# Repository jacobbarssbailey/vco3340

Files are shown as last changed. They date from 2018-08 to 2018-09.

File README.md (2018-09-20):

# VCO3340
This project provides tested plans for a 6HP Eurorack-format CEM3340 [CoolAudio 3340] VCO synthesizer module.

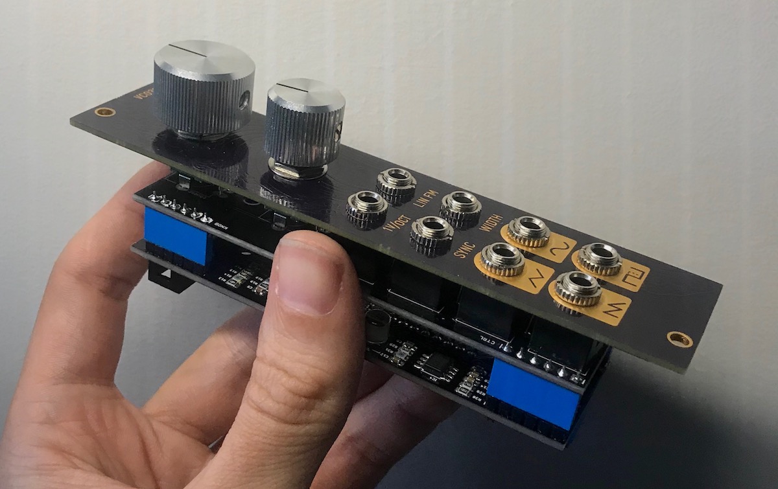
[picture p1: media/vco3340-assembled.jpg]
Assembled module


### Inputs
- V/OCT: Exponential (1V per octave) pitch input
- Lin FM: Linear frequency modulation
- Sync: Hard sync oscillator to external signal; requires audio-rate signal at approx. ±5V.
- Width: Set duty cycle of pulse output from 0-100% with ±2.5V signal; normalled to 0V, i.e. square wave output

### Outputs
All oscillator outputs (Sine, Triangle, Sawtooth, and Pulse) range from ±5V. The pulse input width is controlled by the Width input, and by default is a 50% duty cycle, i.e. Square wave.

## BOM 

Qty | Value            | Device                  | Package             | Parts                                                |
--- | ---------------- | ----------------------- | ------------------- | ---------------------------------------------------- |
2   | 10KΩ             | Pot (Alpha 9mm)         | 6mm                 | COURSE, FINE                                         |
8   | 3.5mm Jacks      |                         | Thonkiconn          | LINFM, PULSE, SAW, SIN, SYNC, TRI, V/OCT, WIDTH      |
4   | M06              | 2.54mm header           | Pin                 | CTRL, KNOB, OUT, POWER                               |
4   | M06              | 2.54mm header           | Socket              | CTRL, KNOB, OUT, POWER                               |
1   | M08X2            | 2.54mm header           | Pin                 | EXPANSION                                            |
3   |                  | 2.54mm                  | Jumper              |                                                      |
1   | M05x2            | 2.54mm header           | Shrouded            | POWER                                                |
2   | 100Ω             | Resistor                | 0805                | R1, R22                                              |
1   | 390Ω             | Resistor                | 0805                | R36                                                  |
2   | 470Ω             | Resistor                | 0805                | R9, R19                                              |
1   | 1KΩ              | Resistor                | 0805                | R32                                                  |
2   | 2.2KΩ            | Resistor                | 0805                | R34, R40                                             |
2   | 3.6KΩ            | Resistor                | 0805                | R23, R25                                             |
1   | 5.6KΩ            | Resistor                | 0805                | R2, R21                                              |
8   | 10KΩ             | Resistor                | 0805                | R5, R10, R27, R35, R38, R39, R41, R42                |
1   | 24KΩ             | Resistor                | 0805                | R20                                                  |
1   | 47KΩ             | Resistor                | 0805                | R3                                                   |
2   | 80KΩ             | Resistor                | 0805                | R28, R29                                             |
5   | 100KΩ            | Resistor                | 0805                | R4, R15, R16, R24, R30                               |
4   | 200KΩ            | Resistor                | 0805                | R14, R18, R26, R31                                   |
1   | 150KΩ            | Resistor                | 0805                | R6                                                   |
3   | 1MΩ              | Resistor                | 0805                | R7, R11, R13                                         |
1   | 1.5MΩ            | Resistor                | 0805                | R8                                                   |
2   | 1.0nF            | Capacitor               | 0805                | C1, C2                                               |
1   | 1.25nF           | Capacitor (CG0)         | 0805                | C6                                                   |
2   | 10nF             | Capacitor               | 0805                | C4, C5                                               |
11  | 100nF            | Capacitor               | 0805                | C3, C10, C11, C12, C13, C14, C15, C18, C19, C21, C22 |
2   | 1µF              | Capacitor               | 0805                | C8, C9                                               |
4   | 47µF             | Capacitor (Pol)         | PANASONIC_C         | C16, C17, C20, C23                                   |
1   | 10KΩ             | Trimpot                 | 2.54mm Multiturn    | SCALE                                                |
1   | 20KΩ             | Trimpot                 | 2.54mm Multiturn    | HIGHFREQ                                             |
1   | 50KΩ             | Trimpot                 | 2.54mm Multiturn    | SYMMETRY                                             |
1   | 100KΩ            | Trimpot                 | 2.54mm Multiturn    | DRIVE                                                |
2   |                  | DIODE                   | SOD-123             | D4, D5                                               |
3   |                  | DIODE                   | SOD-323             | D1, D2, D3                                           |
2   | 3904             | Transistor (NPN)        | SOT23               | Q1, Q2                                               |
1   |                  | LM79L05A                | SOT89               | U1                                                   |
1   |                  | MC78L05A                | SOT89               | U2                                                   |
1   | TL071            | OPAMP-SINGLE            | SO08                | IC1                                                  |
1   |                  | V3340/CEM3340           | SO16                | IC2                                                  |
1   |                  | LM397                   | SOT23-5             | IC3                                                  |
2   | TL072            | OPAMP-DUAL              | SO08                | IC4, IC5                                             |

## Notes on assembly:
1. The rear expansion header is not optional; the V/Oct, Pulse Width, and Soft Sync inputs *must* be connected to ground for proper operation
1. Non-shrouded headers may be used for the Power connector, but this makes it easier to invert the cable polarity, with potentially unpleasant results.

## First time setup
The four trim potentiometers must be set up before use. The following procedure is recommended:
1. Confirm that the V/Oct, Pulse Width, and Soft Sync inputs on the expansion header are connected to the neighboring ground pin (with jumpers)
1. Turn HIGHFREQ all the way down. The middle pin should be shorted to ground.
1. Adjust SCALE until V/Oct input tracks at 1V per octave from 40-60Hz to ≅2Khz. This step is the most difficult, but its critical for tuning. If available, compare against a reference VCO with good tracking. Alternative methods include measuring the pulse output with a frequency counter, or measuring with an external tuner.
1. Adjust HIGHFREQ up until higher frequencies track equally well.
1. Measure the SINE output. Adjust DRIVE and SYMMETRY until the output sounds like a Sine Wave. Using an Oscilloscope may make this easiest, but its not critical and your ears are an equally good reference.

## Expansion header

While the module is an excellent standalone module, the rear expansion header may be used to add additional controls or further manipulate outputs.

It can provide power rails to a sister module, but the ±5V rails should be limited to <50mA.

The external V/Oct pin duplicates the front-panel input. The Width input sets the default pulse width. The Soft Sync input is ready to use as is, and expects ±5V audio rate signals as input.

All output waveforms are provided for additional waveshaping.

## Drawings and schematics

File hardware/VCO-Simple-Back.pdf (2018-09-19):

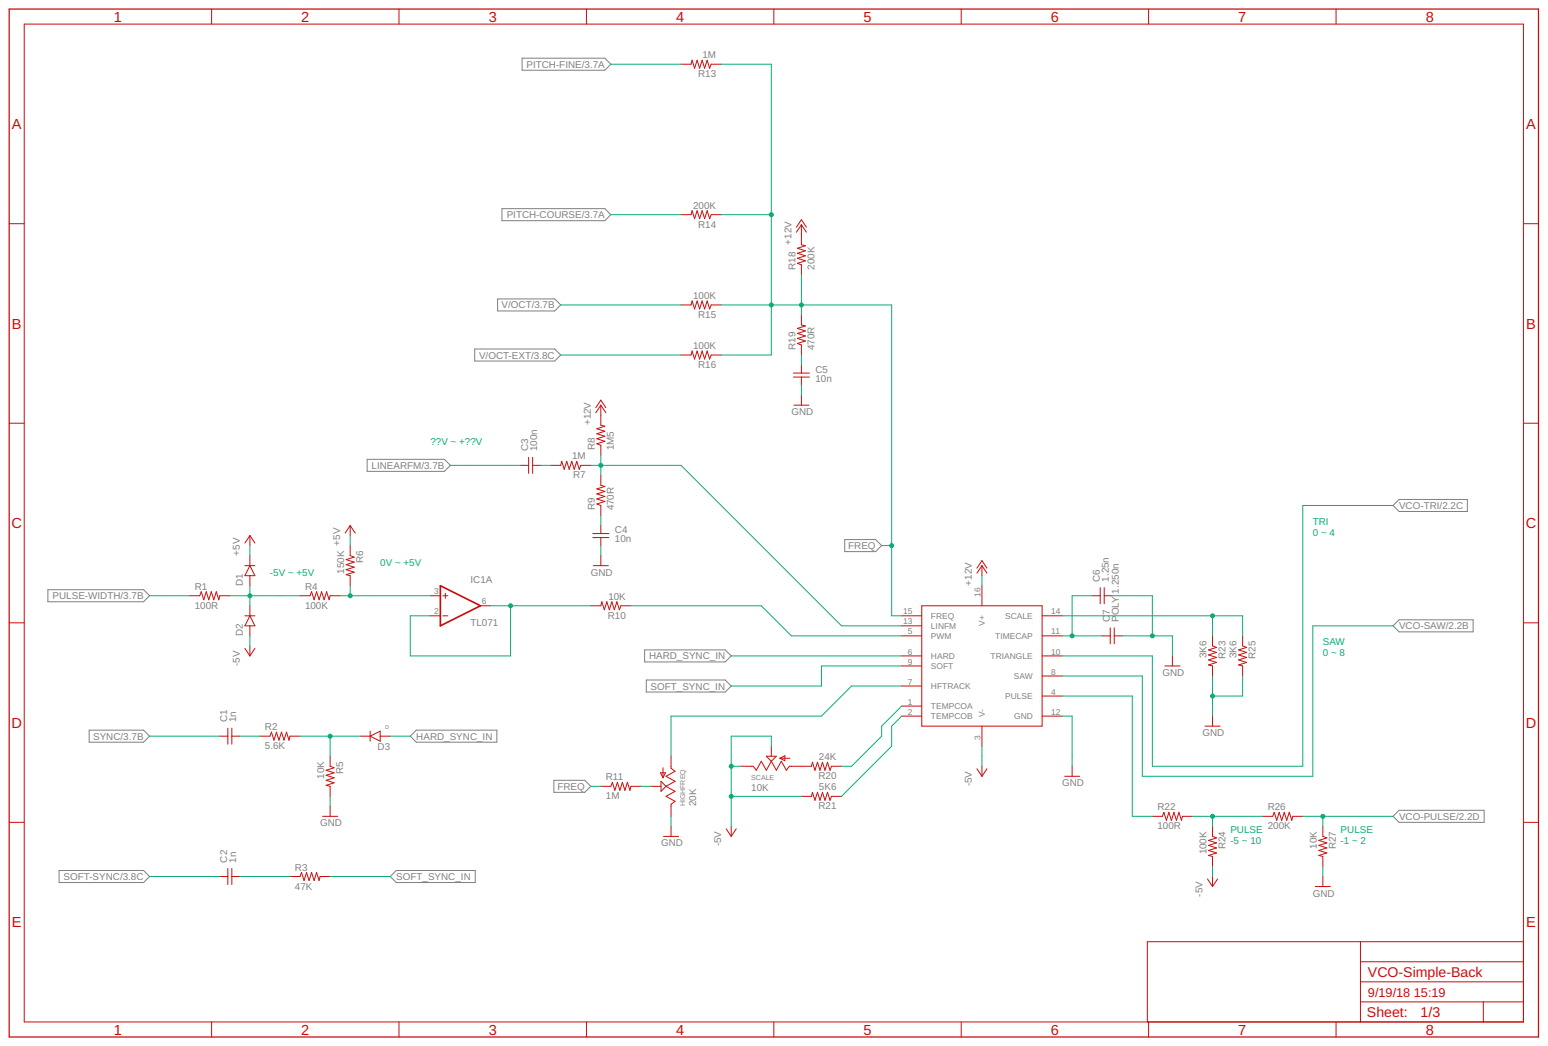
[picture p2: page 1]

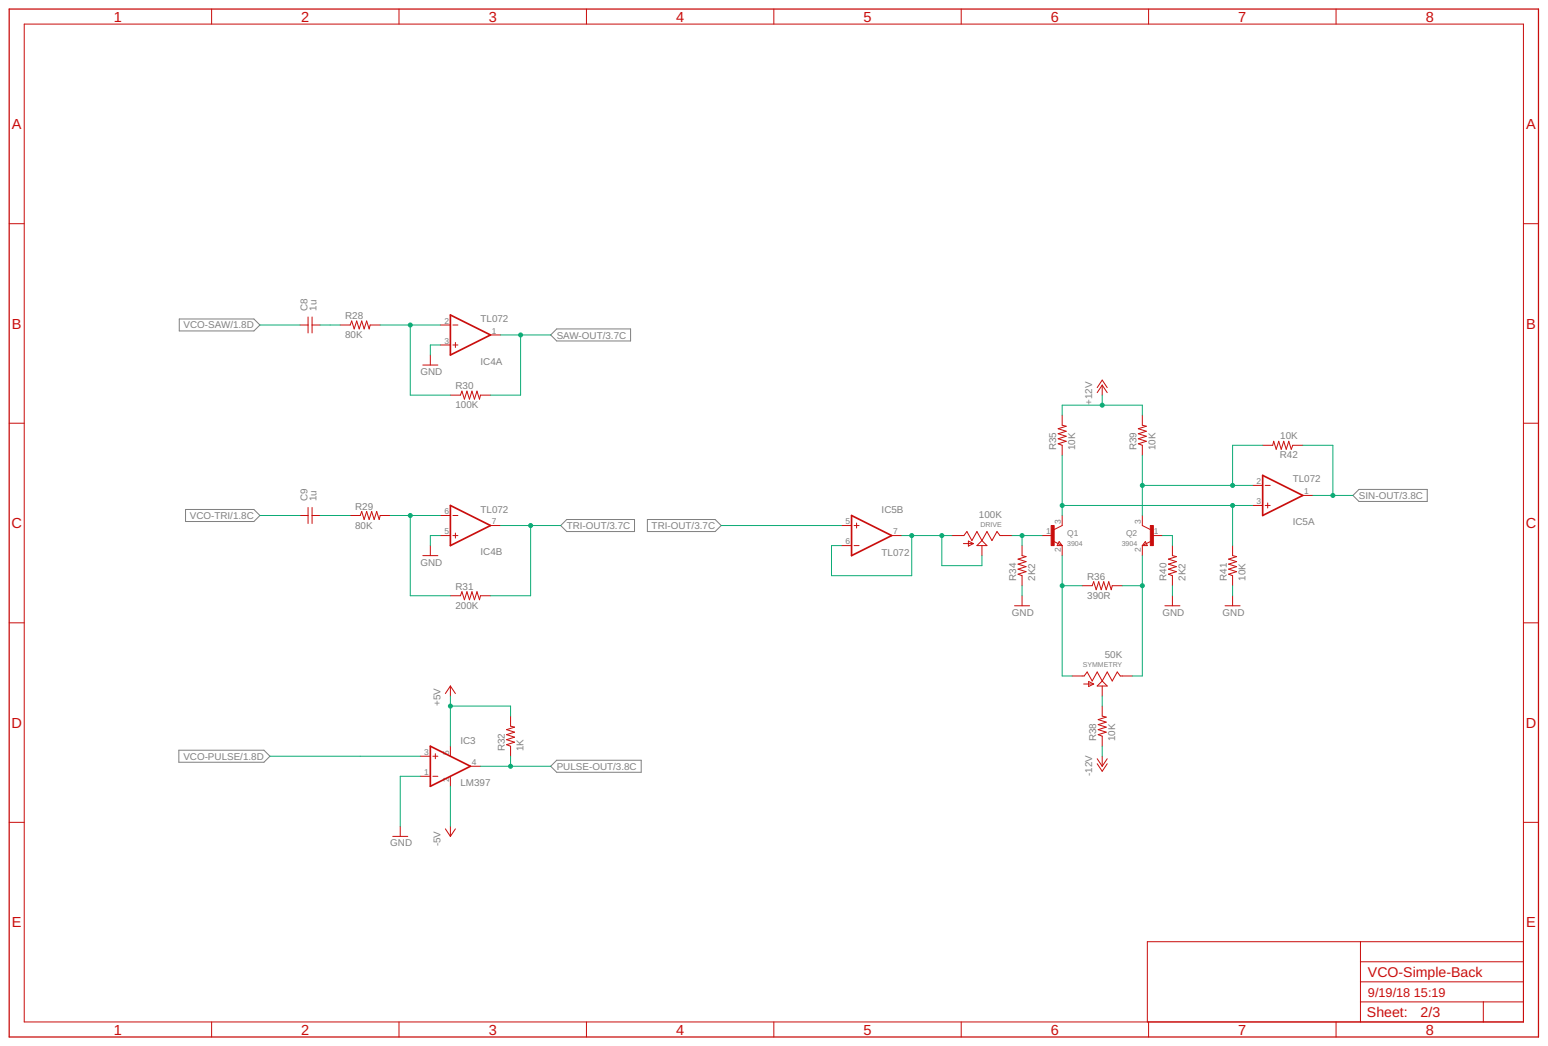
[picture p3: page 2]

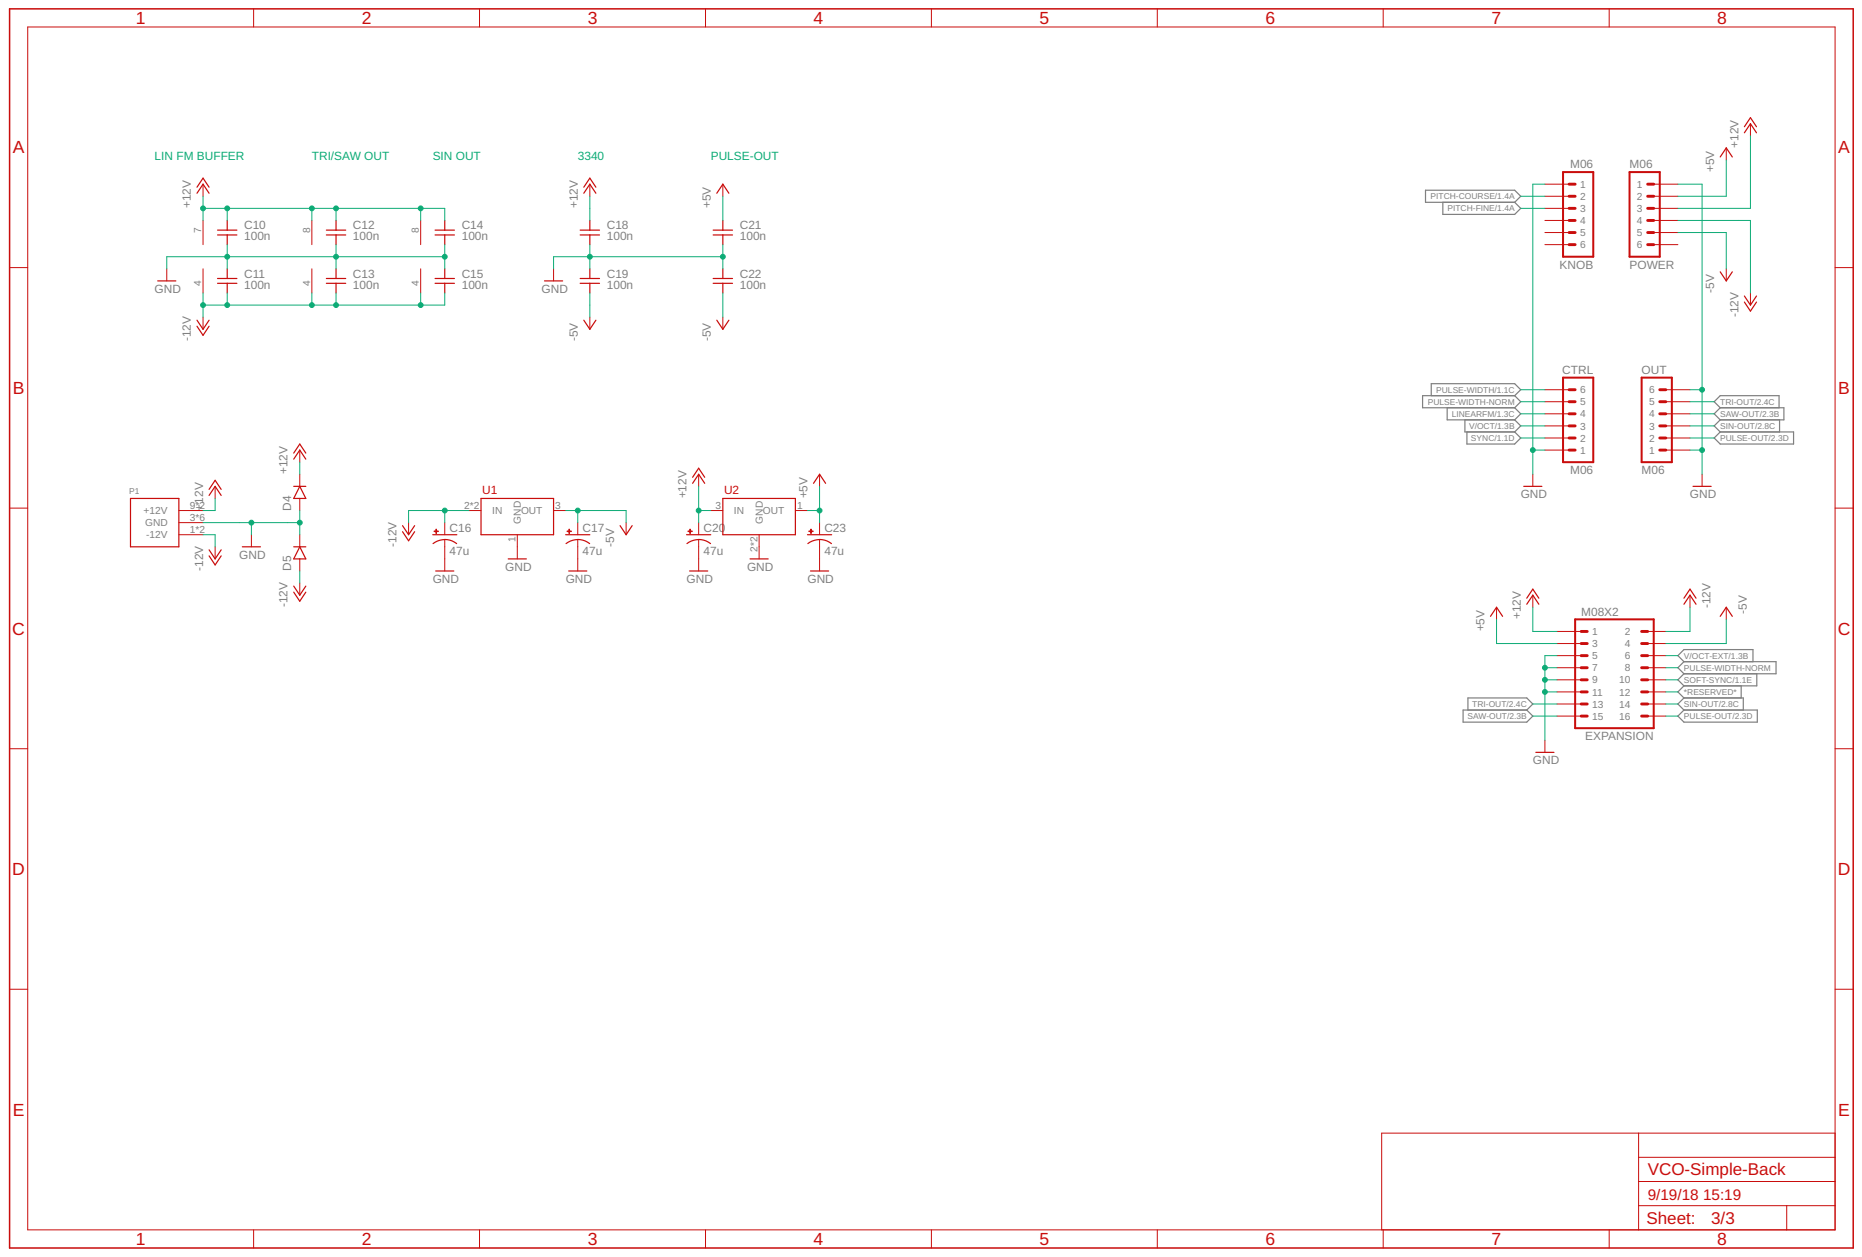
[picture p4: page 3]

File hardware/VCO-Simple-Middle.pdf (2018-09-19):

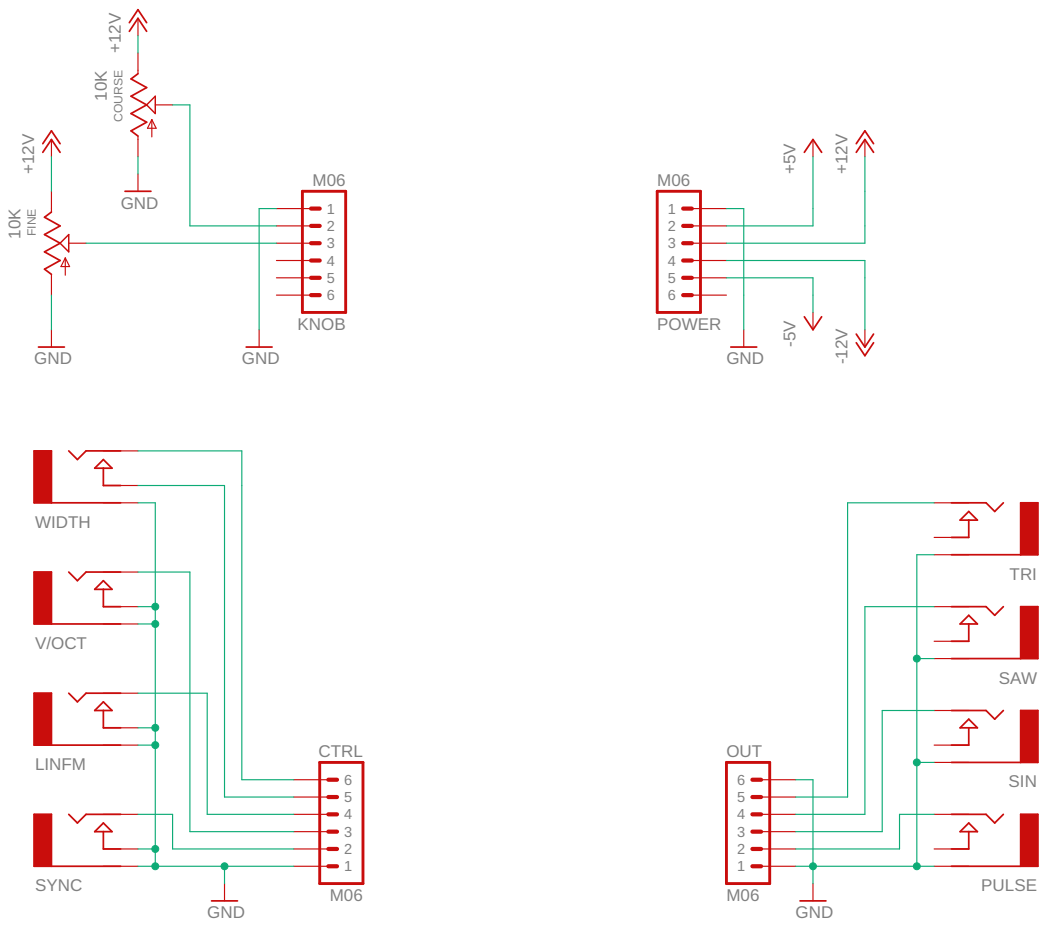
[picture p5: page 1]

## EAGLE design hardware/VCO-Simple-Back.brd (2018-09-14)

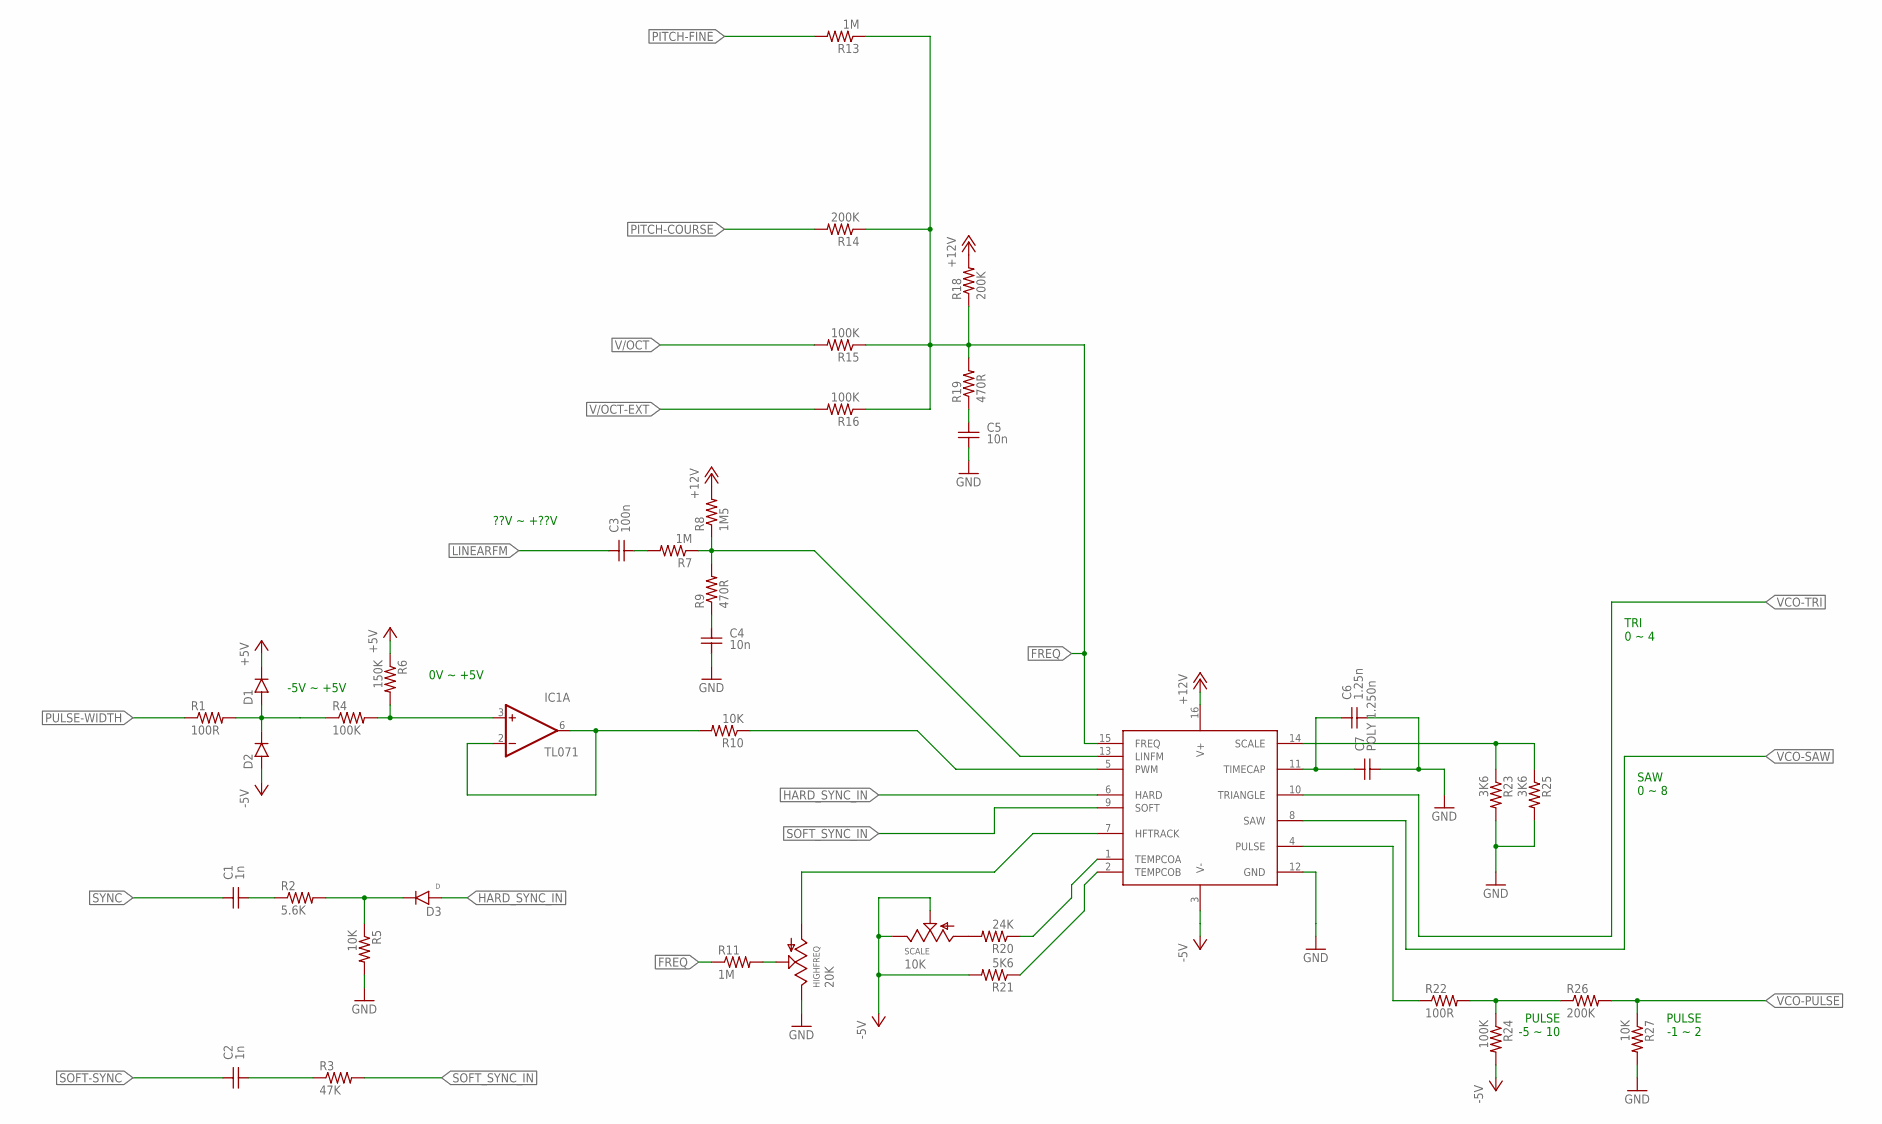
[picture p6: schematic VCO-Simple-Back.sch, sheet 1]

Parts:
C1, C2: 1n; C-0805
C3: 100n; C-0805
C4, C5: 10n; C-0805
C6: 1.25n; C-0805
C7: POLY 1.250n; CAP-5MM
D1, D2: DIODESOD-323; SOD-323
D3: D; SOD-323
HIGHFREQ: 20K; POT-TRIM-MULTI-V
IC1: TL071; SO08
IC2: V3340SO16; SO16
R1, R22: 100R; R-0805-MILL
R2: 5.6K; R-0805-MILL
R3: 47K; R-0805-MILL
R4, R15, R16, R24: 100K; R-0805-MILL
R5, R10, R27: 10K; R-0805-MILL
R6: 150K; R-0805-MILL
R7, R11, R13: 1M; R-0805-MILL
R8: 1M5; R-0805-MILL
R9, R19: 470R; R-0805-MILL
R14, R18, R26: 200K; R-0805-MILL
R20: 24K; R-0805-MILL
R21: 5K6; R-0805-MILL
R23, R25: 3K6; R-0805-MILL
SCALE: 10K; POT-TRIM-MULTI-V

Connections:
+5V: D1.K (C), R6.P$1 (1); also elsewhere on the board
+12V: IC2.16 (V+), R8.P$2 (2), R18.P$2 (2); also elsewhere on the board
-5V: D2.A, IC2.3 (V-), R21.P$2 (2), R24.P$2 (2), SCALE.B (E), SCALE.W (S); also elsewhere on the board
FREQ: IC2.15 (FREQ), R11.P$1 (1), R13.P$1 (1), R14.P$1 (1), R15.P$1 (1), R16.P$1 (1), R18.P$1 (1), R19.P$2 (2)
GND: C4.2, C5.2, C6.2, C7.2, HIGHFREQ.B (E), IC2.12 (GND), R5.P$2 (2), R23.P$2 (2), R25.P$2 (2), R27.P$2 (2); also elsewhere on the board
HARD_SYNC_IN: D3.A, IC2.6 (HARD)
LINEARFM: C3.1; also elsewhere on the board
unnamed: IC2.5 (PWM), R10.P$1 (1)
unnamed: C6.1, C7.1, IC2.11 (TIMECAP)
unnamed: HIGHFREQ.W (S), R11.P$2 (2)
unnamed: R20.P$2 (2), SCALE.A
unnamed: IC2.2 (TEMPCOB), R21.P$1 (1)
unnamed: D3.K (C), R2.P$2 (2), R5.P$1 (1)
unnamed: IC2.14 (SCALE), R23.P$1 (1), R25.P$1 (1)
unnamed: C5.1, R19.P$1 (1)
unnamed: C3.2, R7.P$2 (2)
unnamed: IC2.13 (LINFM), R7.P$1 (1), R8.P$1 (1), R9.P$2 (2)
unnamed: C4.1, R9.P$1 (1)
unnamed: HIGHFREQ.A, IC2.7 (HFTRACK)
unnamed: IC2.1 (TEMPCOA), R20.P$1 (1)
unnamed: D1.A, D2.K (C), R1.P$2 (2), R4.P$1 (1)
unnamed: R22.P$2 (2), R24.P$1 (1), R26.P$1 (1)
unnamed: C1.2, R2.P$1 (1)
unnamed: C2.2, R3.P$1 (1)
unnamed: IC1.3 (+IN), R4.P$2 (2), R6.P$2 (2)
PITCH-COURSE: R14.P$2 (2); also elsewhere on the board
PITCH-FINE: R13.P$2 (2); also elsewhere on the board
PULSE: IC2.4 (PULSE), R22.P$1 (1)
PULSE-WIDTH: R1.P$1 (1); also elsewhere on the board
PWMIN: IC1.2 (-IN), IC1.6 (OUT), R10.P$2 (2)
SOFT-SYNC: C2.1; also elsewhere on the board
SOFT_SYNC_IN: IC2.9 (SOFT), R3.P$2 (2)
SYNC: C1.1; also elsewhere on the board
V/OCT: R15.P$2 (2); also elsewhere on the board
V/OCT-EXT: R16.P$2 (2); also elsewhere on the board
VCO-PULSE: R26.P$2 (2), R27.P$1 (1); also elsewhere on the board
VCO-SAW: IC2.8 (SAW); also elsewhere on the board
VCO-TRI: IC2.10 (TRIANGLE); also elsewhere on the board

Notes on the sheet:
TRI 0 ~ 4
SAW 0 ~ 8
PULSE -5 ~ 10
PULSE -1 ~ 2
-5V ~ +5V
0V ~ +5V
??V ~ +??V

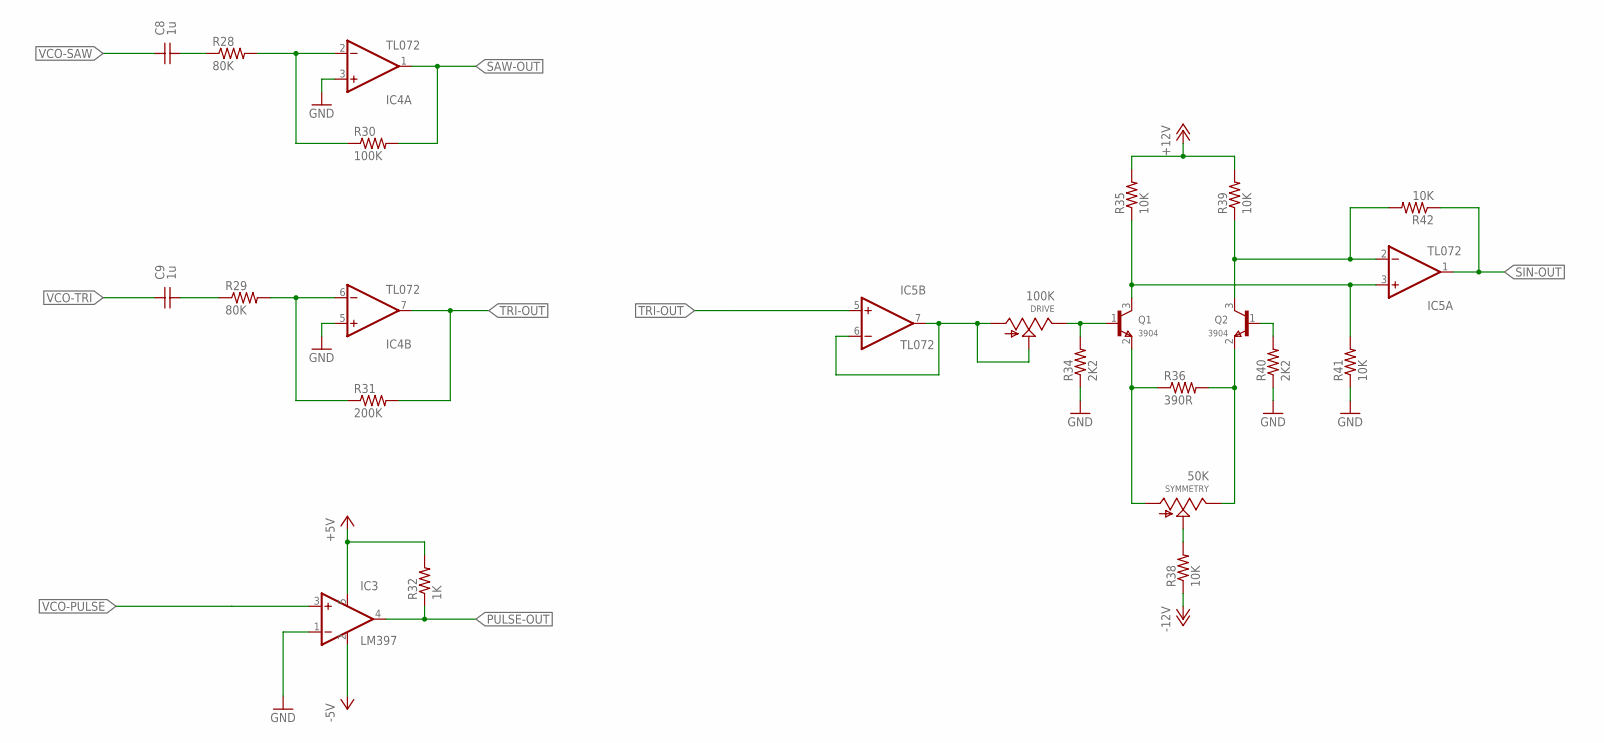
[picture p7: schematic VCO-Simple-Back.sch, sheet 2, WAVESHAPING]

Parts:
C8, C9: 1u; C-0805
DRIVE: 100K; POT-TRIM-MULTI-V
IC3: LM397; SOT23-5
IC4, IC5: TL072; SO08
Q1, Q2: 3904; SOT23
R28, R29: 80K; R-0805-MILL
R30: 100K; R-0805-MILL
R31: 200K; R-0805-MILL
R32: 1K; R-0805-MILL
R34, R40: 2K2; R-0805-MILL
R35, R38, R39, R41, R42: 10K; R-0805-MILL
R36: 390R; R-0805-MILL
SYMMETRY: 50K; POT-TRIM-MULTI-V

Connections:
+5V: IC3.5 (V+), R32.P$2 (2); also elsewhere on the board
+12V: R35.P$2 (2), R39.P$2 (2); also elsewhere on the board
-5V: IC3.2 (GND); also elsewhere on the board
-12V: R38.P$1 (1); also elsewhere on the board
GND: IC3.1 (-IN), IC4.3 (+IN), IC4.5 (+IN), R34.P$1 (1), R40.P$1 (1), R41.P$1 (1); also elsewhere on the board
unnamed: C8.2, R28.P$1 (1)
unnamed: C9.2, R29.P$1 (1)
unnamed: IC4.6 (-IN), R29.P$2 (2), R31.P$1 (1)
unnamed: IC4.2 (-IN), R28.P$2 (2), R30.P$1 (1)
unnamed: DRIVE.A, DRIVE.W (S), IC5.6 (-IN), IC5.7 (OUT)
unnamed: R38.P$2 (2), SYMMETRY.W (S)
unnamed: DRIVE.B (E), Q1.1 (B), R34.P$2 (2)
unnamed: Q1.2 (E), R36.P$1 (1), SYMMETRY.A
unnamed: Q2.2 (E), R36.P$2 (2), SYMMETRY.B (E)
unnamed: Q2.1 (B), R40.P$2 (2)
unnamed: IC5.2 (-IN), Q2.3 (C), R39.P$1 (1), R42.P$2 (2)
unnamed: IC5.3 (+IN), Q1.3 (C), R35.P$1 (1), R41.P$2 (2)
PULSE-OUT: IC3.4 (OUT), R32.P$1 (1); also elsewhere on the board
SAW-OUT: IC4.1 (OUT), R30.P$2 (2); also elsewhere on the board
SIN-OUT: IC5.1 (OUT), R42.P$1 (1); also elsewhere on the board
TRI-OUT: IC4.7 (OUT), IC5.5 (+IN), R31.P$2 (2); also elsewhere on the board
VCO-PULSE: IC3.3 (+IN); also elsewhere on the board
VCO-SAW: C8.1; also elsewhere on the board
VCO-TRI: C9.1; also elsewhere on the board

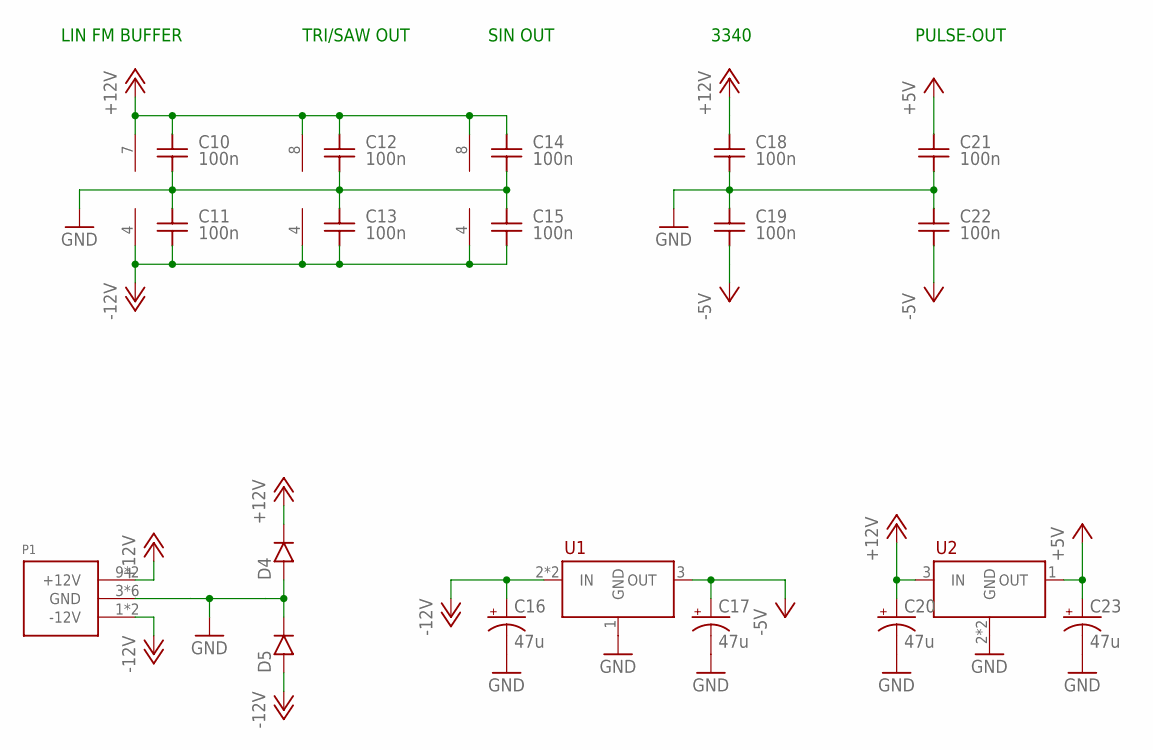
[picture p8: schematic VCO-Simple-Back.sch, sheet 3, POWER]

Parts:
C10, C11, C12, C13, C14, C15, C18, C19, C21, C22: 100n; C-0805
C16, C17, C20, C23: 47u; PANASONIC_C
D4, D5: DIODESOD-123; SOD-123
IC1: TL071; SO08
IC4, IC5: TL072; SO08
P1: POWER_SIMPLE10_SHROUDED; POWER_10_SHROUDED
U1: LM79L05A; SOT89
U2: MC78L05A; SOT89

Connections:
+5V: C21.1, C23.+, U2.1 (OUT); also elsewhere on the board
+12V: C10.1, C12.1, C14.1, C18.1, C20.+, D4.K (C), IC1.7 (V+), IC4.8 (V+), IC5.8 (V+), P1.9 (+12V), P1.10 (+12V), U2.3 (IN); also elsewhere on the board
-5V: C17.+, C19.2, C22.2, U1.3 (OUT); also elsewhere on the board
-12V: C11.2, C13.2, C15.2, C16.+, D5.A, IC1.4 (V-), IC4.4 (V-), IC5.4 (V-), P1.1 (-12V), P1.2 (-12V), U1.2 (IN), U1.2B (IN); also elsewhere on the board
GND: C10.2, C11.1, C12.2, C13.1, C14.2, C15.1, C16.-, C17.-, C18.2, C19.1, C20.-, C21.2, C22.1, C23.-, D4.A, D5.K (C), P1.3 (GND), P1.4 (GND), P1.5 (GND), P1.6 (GND), P1.7 (GND), P1.8 (GND), U1.1 (GND), U2.2 (GND), U2.2B (GND); also elsewhere on the board

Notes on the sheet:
LIN FM BUFFER
3340
TRI/SAW OUT
PULSE-OUT
SIN OUT

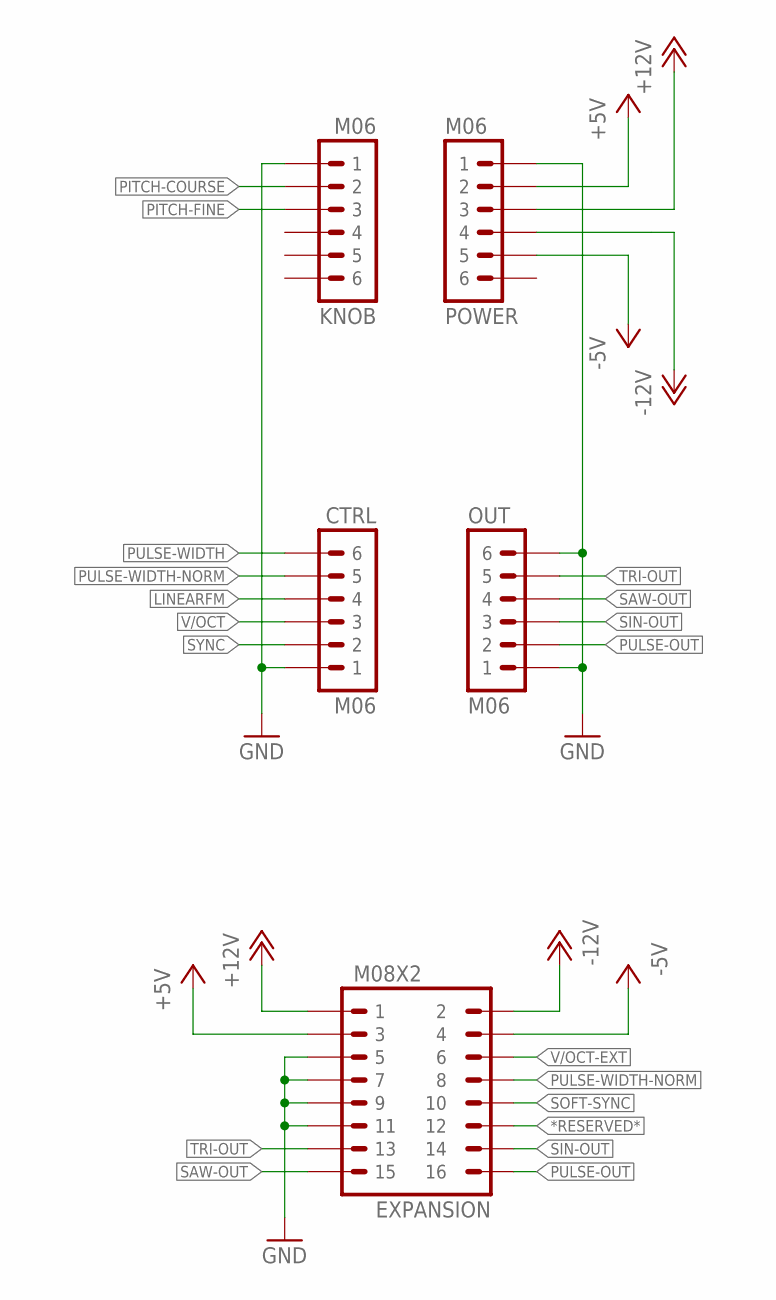
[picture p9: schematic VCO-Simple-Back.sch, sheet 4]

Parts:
CTRL: M06
EXPANSION: M08X2
KNOB: M06
OUT: M06
POWER: M06

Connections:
*RESERVED*: EXPANSION.12
+5V: EXPANSION.3, POWER.2; also elsewhere on the board
+12V: EXPANSION.1, POWER.3; also elsewhere on the board
-5V: EXPANSION.4, POWER.5; also elsewhere on the board
-12V: EXPANSION.2, POWER.4; also elsewhere on the board
GND: CTRL.1, EXPANSION.5, EXPANSION.7, EXPANSION.9, EXPANSION.11, KNOB.1, OUT.1, OUT.6, POWER.1; also elsewhere on the board
LINEARFM: CTRL.4; also elsewhere on the board
PITCH-COURSE: KNOB.2; also elsewhere on the board
PITCH-FINE: KNOB.3; also elsewhere on the board
PULSE-OUT: EXPANSION.16, OUT.2; also elsewhere on the board
PULSE-WIDTH: CTRL.6; also elsewhere on the board
PULSE-WIDTH-NORM: CTRL.5, EXPANSION.8
SAW-OUT: EXPANSION.15, OUT.4; also elsewhere on the board
SIN-OUT: EXPANSION.14, OUT.3; also elsewhere on the board
SOFT-SYNC: EXPANSION.10; also elsewhere on the board
SYNC: CTRL.2; also elsewhere on the board
TRI-OUT: EXPANSION.13, OUT.5; also elsewhere on the board
V/OCT: CTRL.3; also elsewhere on the board
V/OCT-EXT: EXPANSION.6; also elsewhere on the board

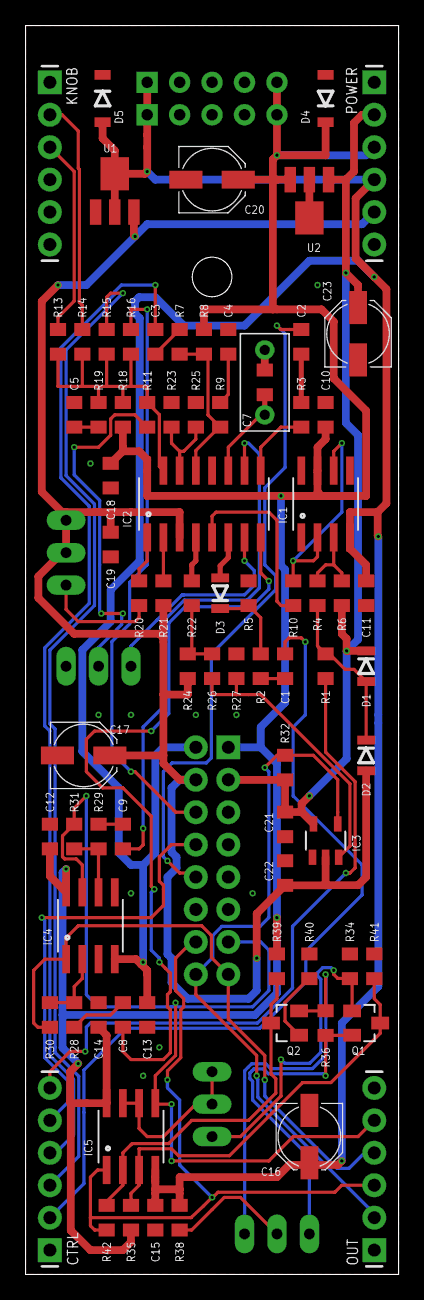
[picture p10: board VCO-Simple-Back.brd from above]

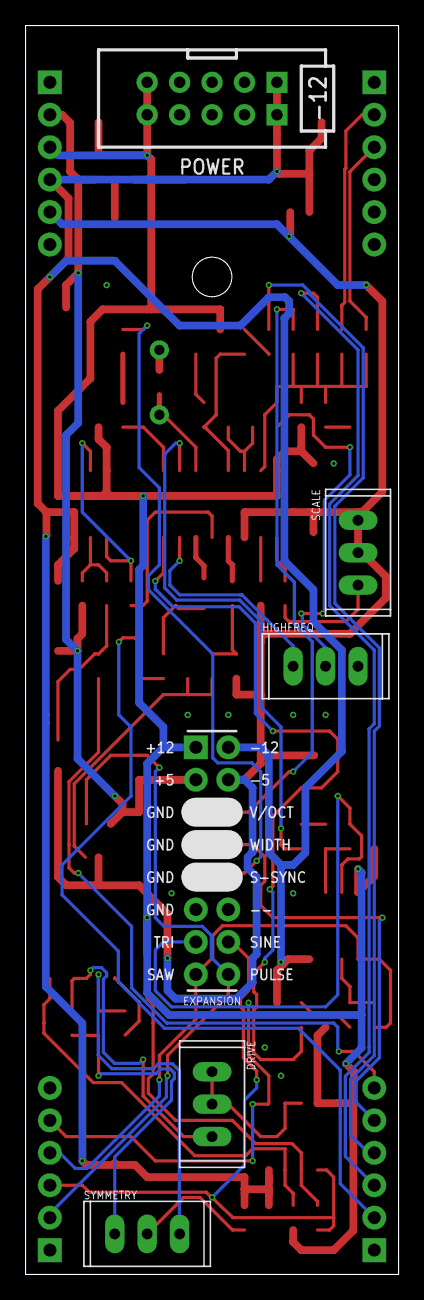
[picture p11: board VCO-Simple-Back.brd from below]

Board: 2 copper layers, 29.2 x 97.8 mm, 85 parts (6 on the bottom side), 56 nets.

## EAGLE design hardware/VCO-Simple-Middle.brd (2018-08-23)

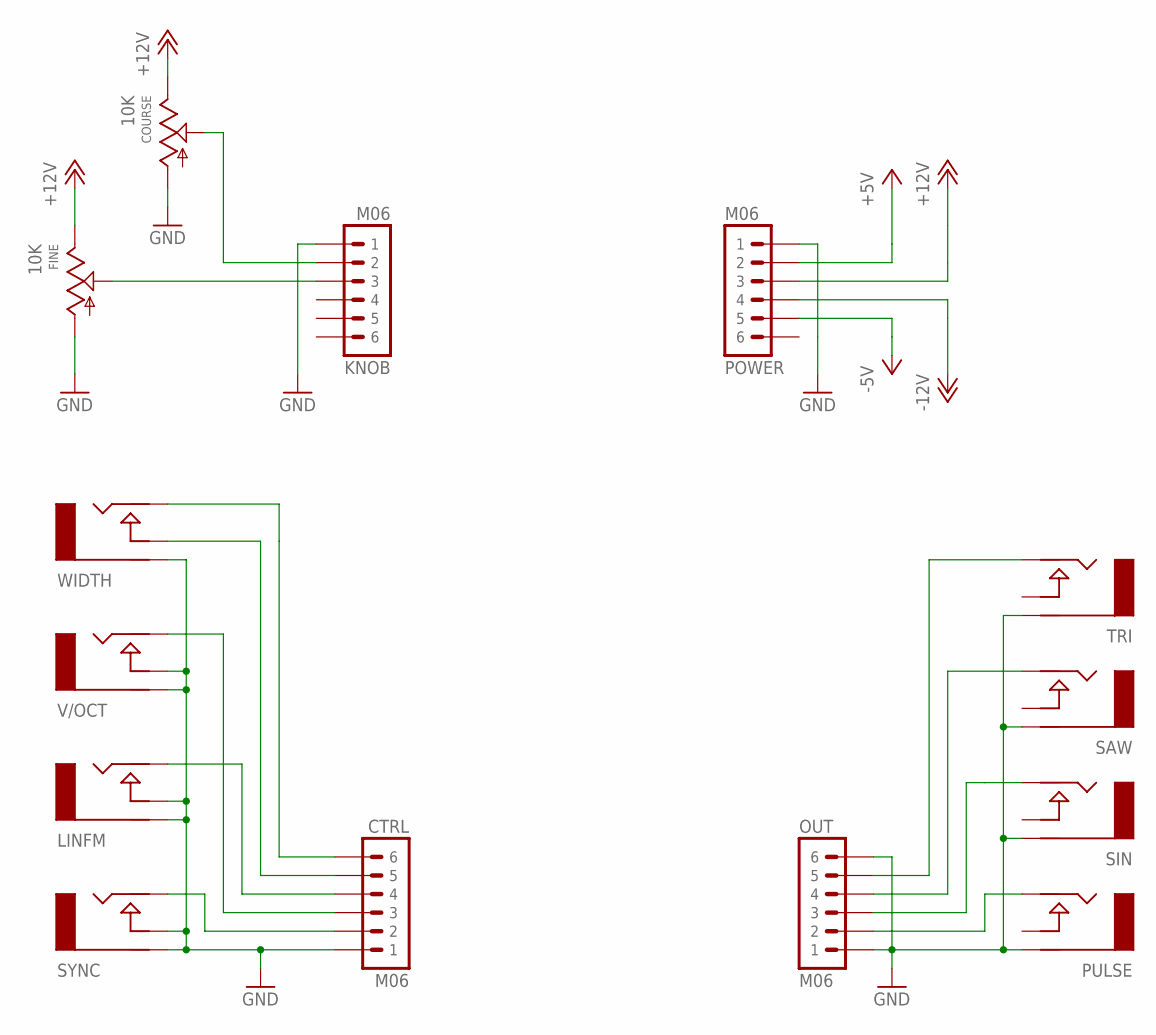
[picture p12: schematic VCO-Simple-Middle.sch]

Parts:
COURSE: 10K; POT-ALPHA-9MM
CTRL: M06
FINE: 10K; POT-ALPHA-9MM
KNOB: M06
LINFM: AUDIO-JACKINLINE; ERTHENVAR-JACK-INLINE
OUT: M06
POWER: M06
PULSE: AUDIO-JACKINLINE; ERTHENVAR-JACK-INLINE
SAW: AUDIO-JACKINLINE; ERTHENVAR-JACK-INLINE
SIN: AUDIO-JACKINLINE; ERTHENVAR-JACK-INLINE
SYNC: AUDIO-JACKINLINE; ERTHENVAR-JACK-INLINE
TRI: AUDIO-JACKINLINE; ERTHENVAR-JACK-INLINE
V/OCT: AUDIO-JACKINLINE; ERTHENVAR-JACK-INLINE
WIDTH: AUDIO-JACKINLINE; ERTHENVAR-JACK-INLINE

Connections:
+5V: POWER.2
+12V: COURSE.B (E), FINE.B (E), POWER.3
-5V: POWER.5
-12V: POWER.4
COURSE: COURSE.W (S), KNOB.2
FINE: FINE.W (S), KNOB.3
GND: COURSE.A, CTRL.1, FINE.A, KNOB.1, LINFM.G (RING), LINFM.N (NORM), OUT.1, OUT.6, POWER.1, PULSE.G (RING), SAW.G (RING), SIN.G (RING), SYNC.G (RING), SYNC.N (NORM), TRI.G (RING), V/OCT.G (RING), V/OCT.N (NORM), WIDTH.G (RING)
LIN: CTRL.4, LINFM.T (TIP)
PULSE: OUT.2, PULSE.T (TIP)
SAW: OUT.4, SAW.T (TIP)
SIN: OUT.3, SIN.T (TIP)
SYNC: CTRL.2, SYNC.T (TIP)
TRI: OUT.5, TRI.T (TIP)
V/OCT: CTRL.3, V/OCT.T (TIP)
WIDTH: CTRL.6, WIDTH.T (TIP)
WIDTH-NORM: CTRL.5, WIDTH.N (NORM)

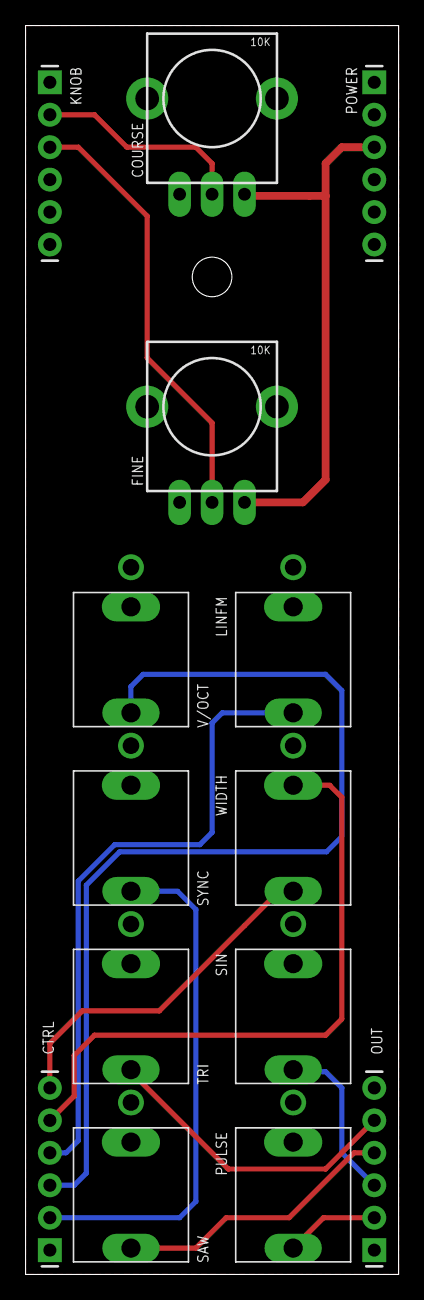
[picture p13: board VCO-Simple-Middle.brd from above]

Board: 2 copper layers, 29.2 x 97.8 mm, 14 parts (0 on the bottom side), 13 nets.

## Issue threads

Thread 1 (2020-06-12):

C7 missing in parts list

Rutger, 2020-06-12:
Firstly, big thanks for sharing this DIY project! I'm assembling this now and I can't wait to try it out. Excellent functionality in a beautiful design. Thanks!

I'm noticing C7 is missing in the BOM. Is that on purpose because it should be left out, or should it be added?

If I understand correctly, C7 is optional because C6 will already play its role. The combination of both will just do a cleaner job at it, right?
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

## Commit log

2018-09-14 revised component values
    [VCO-Simple-Back.brd, VCO-Simple-Back.sch]
2018-09-14 updated readme with description, bom, assembly instructions
2018-09-14 add image, fix bom table dividers
2018-09-19 add page frames
    [VCO-Simple-Back.sch, VCO-Simple-Middle.sch]
2018-09-19 schematic pdfs
